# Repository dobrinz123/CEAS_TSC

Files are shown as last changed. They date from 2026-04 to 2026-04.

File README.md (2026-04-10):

# InkTime v6 — E-Paper Smartwatch

Smartwatch cu ecran e-paper, Bluetooth Low Energy si baterie LiPo reincarcabila prin USB-C.

**Curs:** TSC (Testarea Sistemelor de Calcul), Anul 3  
**Tool:** Fusion 360 Electronics (EAGLE format)  
**Producator:** JLCPCB — 4 straturi, stackup JLC04161H-7628, finish ENIG

---

## Block Diagram

```
                        USB-C (J4)
                           |
                     USBLC6-2SC6Y (D4)
                       ESD Protection
                           |
            +--------------+---------------+
            |                              |
      BQ25180 (IC3)                   nRF52840 (U1)
      LiPo Charger                  BLE5 + ARM M4F
      I2C addr 0x6A                    64MHz MCU
            |                     /    |    |    \
        LiPo Battery         SPI   I2C  GPIO  USB
            |                  |     |    |
      MAX17048 (U1)        E-Paper  Bus  Buttons
      Fuel Gauge           Display  |    (3x SW)
      I2C addr 0x36       1.54"    |
            |              GDEW0154 |
      RT6160 (IC2)              +---+---+---+
      Buck-Boost DC/DC         |   |   |   |
      3.3V Output          BMA421 MAX  BQ  DRV2605
                           IMU  17048 25180 Haptic
                           0x18  0x36 0x6A  0x5A
                                            |
                                        Shaker Motor
                                        LCM1027B3605F
```

---

## Specificatii

| Parametru | Valoare |
|---|---|
| MCU | nRF52840-QIAA (BLE 5.0, ARM Cortex-M4F, 64MHz) |
| Display | GDEW0154M09 1.54" e-paper (200x200px) |
| Baterie | LiPo 250mAh, BQ25180 charger |
| IMU | BMA421 accelerometru + step counter |
| Haptics | DRV2605L + LCM1027B3605F motor ERM |
| Fuel Gauge | MAX17048 LiPo gauge |
| DC/DC | RT6160 buck-boost, 3.3V output |
| USB | USB-C (KH-TYPE-C-16P), USBLC6-2SC6Y ESD |
| Debug | TC2030-IDC TagConnect SWD |
| PCB | 46x35mm, 4 straturi, 1.6mm, ENIG |

---

## Stackup PCB

| Strat | Functie | Cupru |
|---|---|---|
| F.Cu (Top) | Semnal + Componente | 1oz (35um) |
| In1.Cu | Plan GND | 0.5oz (17.5um) |
| In2.Cu | Plan 3V3 | 0.5oz (17.5um) |
| B.Cu (Bottom) | Rutare semnal | 1oz (35um) |

---

## Structura Proiect

```
Hardware/
|-- inktime_v6.sch                # Schematic EAGLE
|-- inktime_v6.brd                # PCB layout (46x35mm, 4 straturi)
Manufacturing/
|-- inktime_v6_gerbers.zip        # Fisiere Gerber pt JLCPCB
|-- inktime_v6_BOM_jlcpcb.csv    # Bill of Materials (part numbers LCSC)
|-- inktime_v6_CPL_jlcpcb.csv    # Pick-and-Place (coordonate componente)
Mechanical/
|-- inktime_v6_cas.f3d            # Model 3D Fusion 360 (carcasa + componente)
|-- inktime_v6.step               # Export STEP
Images/
|-- Baterie.png                   # Model 3D baterie LiPo
|-- Carcasa_ceas.png              # Randare carcasa (vedere 1)
|-- Carcasa_ceas_2.png            # Randare carcasa (vedere 2)
|-- Ecran_e_paper.png             # Model 3D ecran e-paper
|-- Model_PCB.png                 # Model 3D PCB cu componente
|-- Motor.png                     # Model 3D motor vibratii
|-- Randare_PCB.png               # Randare PCB complet
LICENSE
README.md
```

---

## Note Fabricatie

- **Producator**: JLCPCB 4 straturi, stackup JLC04161H-7628
- **Finish**: ENIG (Electroless Nickel Immersion Gold)
- **Grosime PCB**: 1.6mm
- **Cupru**: 1oz exterior, 0.5oz interior
- **Componente**: Toate pe stratul TOP, asamblare SMT
- **Montare manuala**: retea matching RF, test pads, conector FPC (J1), TagConnect (J3), motor vibratii

---

## Autor

Dobrin David — TSC (Testarea Sistemelor de Calcul), 2026

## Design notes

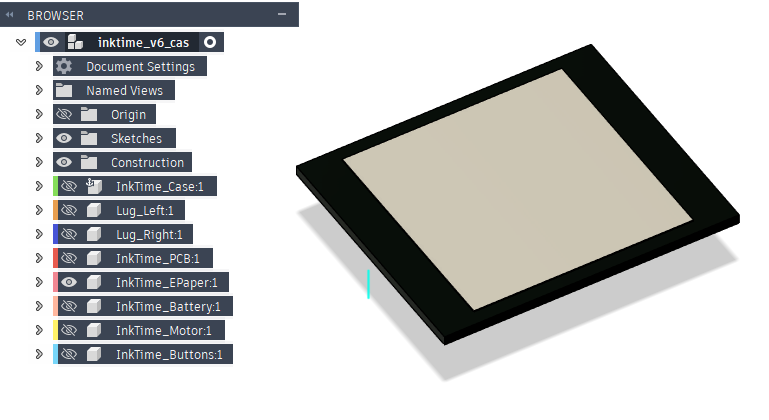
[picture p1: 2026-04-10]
Images/Ecran_e_paper.png

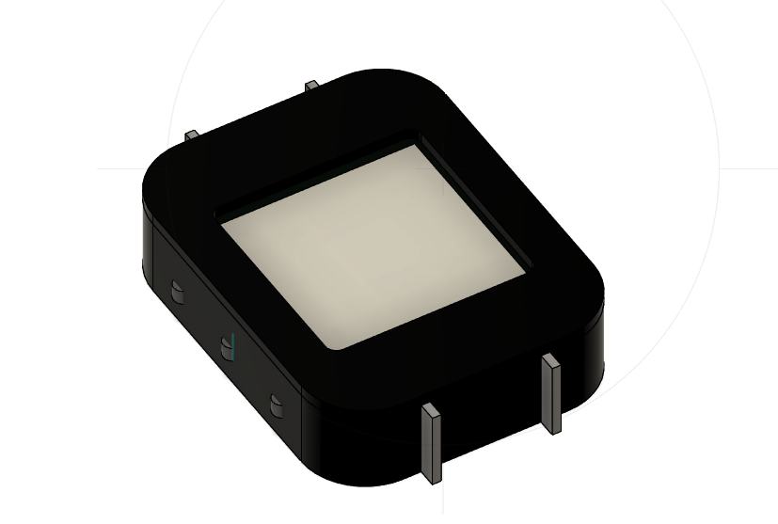
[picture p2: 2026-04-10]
Images/Carcasa_ceas_2.png

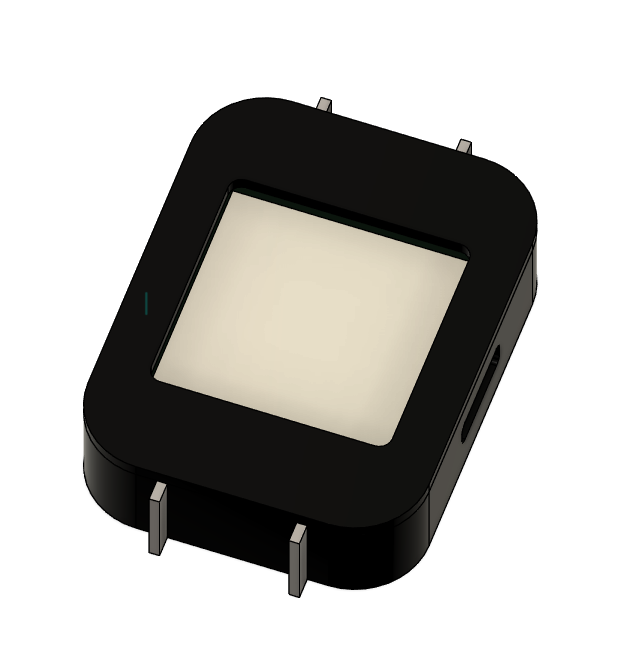
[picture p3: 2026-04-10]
Images/Carcasa_ceas.png

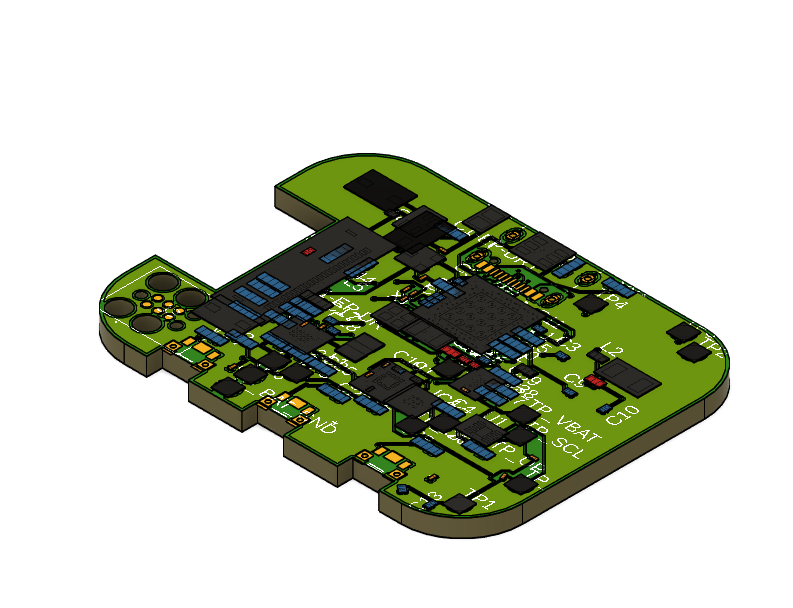
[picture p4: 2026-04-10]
Images/Randare_PCB.png

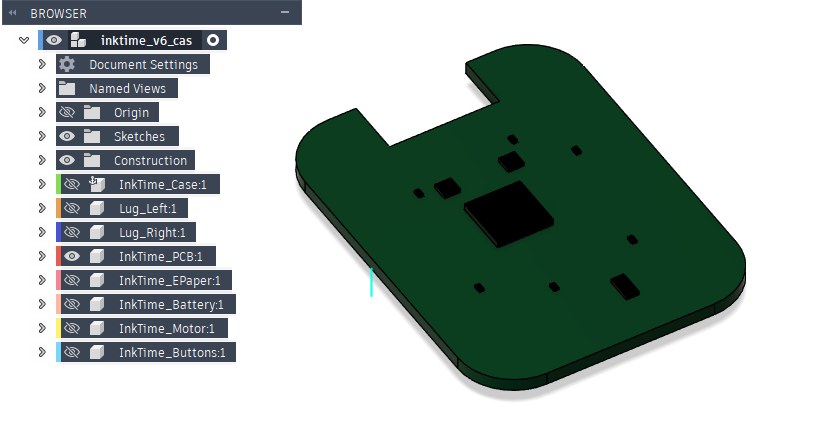
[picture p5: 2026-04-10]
Images/Model_PCB.png

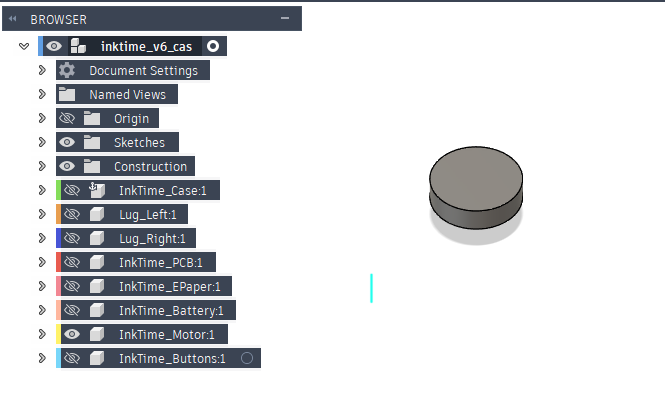
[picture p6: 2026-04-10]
Images/Motor.png

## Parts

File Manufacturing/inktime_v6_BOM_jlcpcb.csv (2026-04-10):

Comment | Designator | Footprint | LCSC Part #
0 | R1,R2,R3 | 0201 | C17168
0 | SJ1 | SJ | C17168
0.1uF | C2,C23,C26,C31 | 0402 | C14663
0.47 | R6 | 0201
1.0uF | C15 | 0402 | C15849
100nF | C12,C19,C5,C7,C8 | 0201 | C14663
100pF | C11 | 0201 | C14858
10K | R10,R11,R12,R13,R14,R16,R8,R9 | 0201 | C25744
10uF | C1-EP-DR,C24,C39 | 0402 | C15712
10uH | L2,L3 | 0402 | C408494
12pF | C17,C18,U$4,U$5 | 0201 | C30379
1pF | C1,C3 | 0201
1uF | C27,C28,C29,C37,C38,C4 | 0402 | C15849
1uF/50V | U$3 | 0201 | C15849
1uF/50V | C32,C34,C35,C36,C40,C41,C42,C43,C44 | 0402 | C15849
2.2 | R7 | 0201 | C25879
2025-10-22_07-23-44_LIBRARY_EVP-AKE31ASW_EVP-AKE31A_PAN | SW1,SW2,SW3 | SW-SMD-3x4
20V/4.2A/52mohm/1.4W | Q2 | SOT23-3
22uF | C25,C33 | 0402 | C59461
2450AT18B100E_2450AT18B100E | ANT1 | 0402 | C89965
3.9nH | U$2 | 0402 | C95912
32.768kHz | X2 | SMD3215 | C32346
32MHz | X1 | SMD3215 | C9001582
3K3 | R4,R5 | 0201 | C25890
4.7uF | C14,C20,C21,C30,C6 | 0402
4.7uF/25V | C1-EP-DR1 | 0402
47nF | C16 | 0201 | C14663
503480-2400_503480-2400 | J1 | FPC-24
68uH | L5 | 0201 | C132330
820pF | C9 | 0201 | C14858
BMA423_BMA423 | IC1 | LGA-12 | C5242966
BQ25180YBGR_BQ25180YBGR | IC3 | DSBGA-8 | C2681936
DRV2605YZFR_DRV2605YZFR | IC4 | DSBGA-12 | C2682232
ESP32_C6_LIBRARY_3_USBLC6-2SC6Y | D4 | SOT-363 | C7519
ESP32_C6_LIBRARY_5_MBR0530 | D1,D2,D3 | SOD-123 | C242214
ESP32_C6_LIBRARY_6_SI1308EDL-T1-GE3 | Q1 | SOT-523 | C145065
ESP32_C6_LIBRARY_MAX17048G+T10 | U1 | DFN8-2x2 | C2682616
KH-TYPE-C-16P_KH-TYPE-C-16P | J4 | USB-C-16P | C165948
MLP2016SR47MT0S1_FTC252012SR47MBCA | L1 | 0402
N.C. | C10,C13,C22 | 0201
NORDIC_NRF_4_NRF52840_QF | U$1 | QFN-73 | C190794
RT6160AWSC_RT6160AWSC | IC2 | WLCSP-15 | C7065276
TC2030-IDC_TC2030-IDC | J3 | TC2030

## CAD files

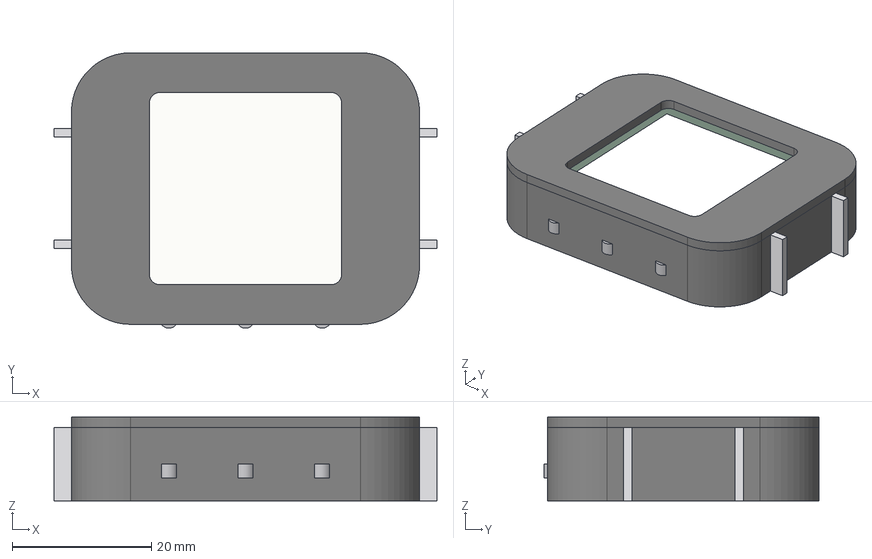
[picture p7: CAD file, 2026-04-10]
Mechanical/inktime_v6.step
55.0 x 39.5 x 12.0 mm

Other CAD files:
Mechanical/inktime_v6_cas.f3d

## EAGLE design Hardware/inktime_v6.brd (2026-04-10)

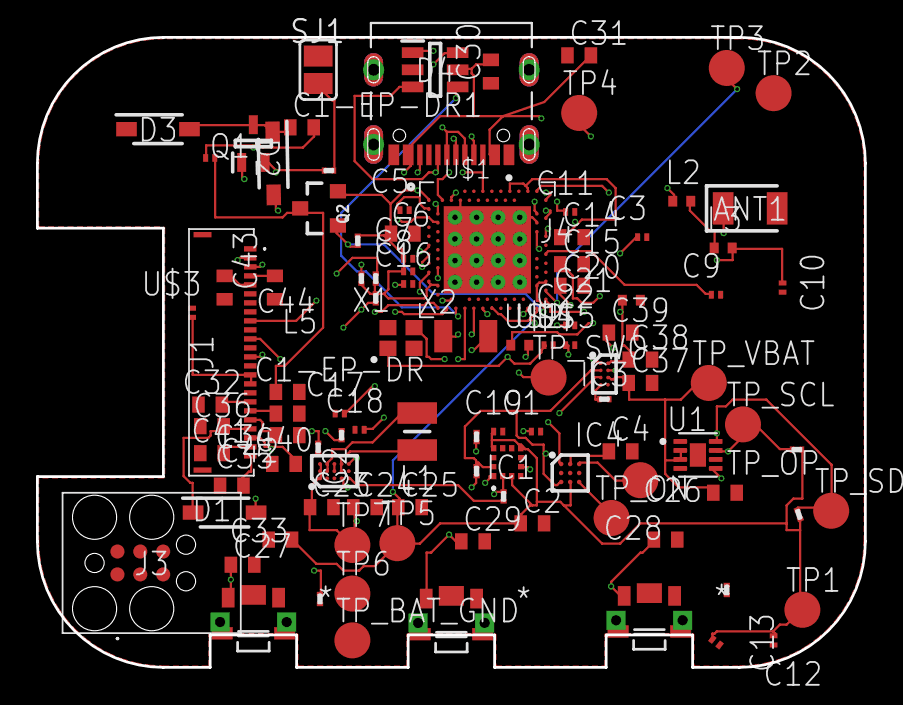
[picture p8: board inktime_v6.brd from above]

Board: 4 copper layers, 46.0 x 35.0 mm, 105 parts (0 on the bottom side), 70 nets.

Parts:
ANT1: 2450AT18B100E_2450AT18B100E; 2450AT18B100E_ANTC3216X140N
C1, C3: 1pF; NORDIC_NRF_3_RESC0201_L
C1-EP-DR, C24, C39: 10uF; ESP32_C6_LIBRARY_1_ESP32_WROVER_EAGLE-LTSPICE_C0402
C1-EP-DR1: 4.7uF/25V; ESP32_C6_LIBRARY_1_ESP32_WROVER_EAGLE-LTSPICE_C0402
C2, C23, C26, C31: 0.1uF; ESP32_C6_LIBRARY_1_ESP32_WROVER_EAGLE-LTSPICE_C0402
C4, C27, C28, C29, C37, C38: 1uF; ESP32_C6_LIBRARY_1_ESP32_WROVER_EAGLE-LTSPICE_C0402
C5, C7, C8, C12, C19: 100nF; NORDIC_NRF_3_RESC0201_L
C6, C14, C20: 4.7µF; ESP32_C6_LIBRARY_1_ESP32_WROVER_EAGLE-LTSPICE_C0402
C9: 820pF; NORDIC_NRF_3_RESC0201_L
C10, C13, C22: N.C.; NORDIC_NRF_3_RESC0201_L
C11: 100pF; NORDIC_NRF_3_RESC0201_L
C15: 1.0µF; ESP32_C6_LIBRARY_1_ESP32_WROVER_EAGLE-LTSPICE_C0402
C16: 47nF; NORDIC_NRF_3_RESC0201_L
C17, C18: 12pF; NORDIC_NRF_3_RESC0201_L
C21: 4.7µF; NORDIC_NRF_3_RESC0402_L
C25, C33: 22uF; ESP32_C6_LIBRARY_1_ESP32_WROVER_EAGLE-LTSPICE_C0402
C30: 4.7uF; ESP32_C6_LIBRARY_1_ESP32_WROVER_EAGLE-LTSPICE_C0402
C32, C34, C35, C36, C40, C41, C42, C43, C44: 1uF/50V; ESP32_C6_LIBRARY_1_ESP32_WROVER_EAGLE-LTSPICE_C0402
D1, D2, D3: ESP32_C6_LIBRARY_5_MBR0530; ESP32_C6_LIBRARY_5_SOD3716X135N
D4: ESP32_C6_LIBRARY_3_USBLC6-2SC6Y; ESP32_C6_LIBRARY_3_SOT95P280X145-6N
IC1: BMA423_BMA423
IC2: RT6160AWSC_RT6160AWSC; RT6160AWSC_BGA15C40P3X5_140X230X60
IC3: BQ25180YBGR_BQ25180YBGR; BQ25180YBGR_BGA8C40P2X4_100X155X50
IC4: DRV2605YZFR_DRV2605YZFR; DRV2605YZFR_BGA9C50P3X3_144X144X62
J1: 503480-2400_503480-2400; 503480-2400_5034802400
J3: TC2030-IDC_TC2030-IDC; TC2030-IDC_TC2030IDC
J4: KH-TYPE-C-16P_KH-TYPE-C-16P; KH-TYPE-C-16P_KINGHELM_KH-TYPE-C-16P
L1: MLP2016SR47MT0S1_FTC252012SR47MBCA; MLP2016SR47MT0S1_INDC2016X100N
L2, L3: 10µH; NORDIC_NRF_2_RESC0402_L
L5: 68uH; NORDIC_NRF_2_RESC0201_L
Q1: ESP32_C6_LIBRARY_6_SI1308EDL-T1-GE3; ESP32_C6_LIBRARY_6_SOT65P210X110-3N
Q2: 20V/4.2A/52mΩ/1.4W; ESP32_C6_LIBRARY_4_ESP32_C6_LIBRARY_4_ESP32_C6_LIBRARY_4_ES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
R1, R2, R3: 0; CPF0201D7K68C1_0201
R4, R5: 3K3; CPF0201D7K68C1_0201
R6: 0.47; CPF0201D7K68C1_0201
R7: 2.2; CPF0201D7K68C1_0201
R8, R9, R10, R11, R12, R13, R14, R16: 10K; CPF0201D7K68C1_0201
SJ1: 0; ESP32_C6_LIBRARY_7_JUMPER_SJ
SW1, SW2, SW3: 2025-10-22_07-23-44_LIBRARY_EVP-AKE31ASW_EVP-AKE3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; 2025-10-22_07-23-44_LIBRARY_SW_EVP-AKE31A_PAN
TP1, TP2, TP3, TP4, TP5, TP6, TP7: HECTOR_WATCH_1_TPTP20R; HECTOR_WATCH_1_TP20R
TP_BAT_GND: HECTOR_WATCH_1_TPTP20R; HECTOR_WATCH_1_TP20R
TP_ON: HECTOR_WATCH_1_TPTP20R; HECTOR_WATCH_1_TP20R
TP_OP: HECTOR_WATCH_1_TPTP20R; HECTOR_WATCH_1_TP20R
TP_SCL: HECTOR_WATCH_1_TPTP20R; HECTOR_WATCH_1_TP20R
TP_SDA: HECTOR_WATCH_1_TPTP20R; HECTOR_WATCH_1_TP20R
TP_SWO: HECTOR_WATCH_1_TPTP20R; HECTOR_WATCH_1_TP20R
TP_VBAT: HECTOR_WATCH_1_TPTP20R; HECTOR_WATCH_1_TP20R
U1: ESP32_C6_LIBRARY_MAX17048G+T10; ESP32_C6_LIBRARY_SON50P200X200X80-9N
U$1: NORDIC_NRF_4_NRF52840_QF; NORDIC_NRF_4_AQFN50P700X700X85_HS-74N
U$2: 3.9nH; NORDIC_NRF_2_RESC0402_L
U$3: 1uF/50V; NORDIC_NRF_3_RESC0201_L
U$4, U$5: 12pF; NORDIC_NRF_3_RESC0201_L
X1: 32MHz; NORDIC_NRF_BT-XTAL_2016_N
X2: 32.768kHz; NORDIC_NRF_1_XTAL_3215_N

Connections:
3V3: C2.1, C6.1, C7.1, C8.1, C12.1, C13.1, C14.1, C19.1, C25.1, C33.1, IC1.3, IC1.7, IC1.10, IC2.E3, IC4.C2, Q2.2, R4.1, R5.1, R10.2, R11.2, R12.2, R16.2, TP1.TP, TP5.TP, U$1.P$A18, U$1.P$A22, U$1.P$AD14, U$1.P$AD23, U$1.P$B1, U$1.P$W1, U$1.P$Y2
ALERT: U1.5, U$1.P$J24
D+: D4.4, U$1.P$AD6
D-: D4.6, U$1.P$AD4
DEC3: C11.1, U$1.P$D23
DEC4_6: C10.1, C15.1, C16.1, L3.2, U$1.P$B5, U$1.P$E24
DN: D4.1, J4.A7, J4.B7
DP: D4.3, J4.A6, J4.B6
EPD: J1.15, J1.16, U$3.2
EPD_3V3: C1-EP-DR.1, L5.1, Q2.3
EPD_BUSY: J1.9, U$1.P$AD12
EPD_CS: J1.12, U$1.P$K2
EPD_DC: J1.11, U$1.P$AD10
EPD_RST: J1.10, U$1.P$AC11
GDR: J1.2, Q1.1, R8.2
GND: C1.2, C1-EP-DR.2, C2.2, C3.2, C4.2, C5.2, C6.2, C7.2, C8.2, C9.2, C10.2, C11.2, C12.2, C13.2, C14.2, C15.2, C16.2, C17.1, C18.1, C19.2, C20.2, C21.2, C22.2, C23.2, C24.2, C25.2, C26.2, C27.2, C28.2, C29.2, C30.1, C31.1, C32.1, C33.2, C34.1, C35.1, C36.1, C37.2, C38.2, C39.2, C40.1, C41.1, C43.1, C44.1, D3.1, D4.2, IC1.8, IC1.9, IC2.B1, IC2.C1, IC2.C2, IC2.C3, IC3.D2, IC4.B1, IC4.B3, J1.8, J1.17, J1.MP1, J1.MP2, J4.A1_B12, J4.A12_B1, J4.SH1, J4.SH2, J4.SH3, J4.SH4, R3.1, R7.1, R8.1, R9.1, R13.1, R14.2, SJ1.1, SW1.1, SW2.1, SW3.1, TP6.TP, TP_BAT_GND.TP, U1.1, U1.4, U1.6, U1.9, U$1.P$74, U$1.P$75, U$1.P$76, U$1.P$77, U$1.P$78, U$1.P$79, U$1.P$80, U$1.P$81, U$1.P$82, U$1.P$83, U$1.P$84, U$1.P$85, U$1.P$86, U$1.P$87, U$1.P$88, U$1.P$89, U$1.P$90, U$1.P$B7, U$1.P$F23, U$3.1, U$4.2, U$5.2, X1.2, X1.4
GND3: IC1.1, R3.2
HAPTIC_EN: IC4.A1, U$1.P$U1
IMU_INT1: IC1.5, U$1.P$N1
IMU_INT2: IC1.6, U$1.P$P2
LX1: IC2.B2, IC2.B3, L1.1
LX2: IC2.D2, IC2.D3, L1.2
MOSI: J1.14, U$1.P$B13
unnamed: C5.1, U$1.P$C1
unnamed: C20.1, U$1.P$AC5
unnamed: ANT1.1, C1.1, C22.1, U$2.2
unnamed: C3.1, U$1.P$H23, U$2.1
unnamed: L2.2, L3.1
unnamed: U$1.P$A23, U$5.1, X1.3
unnamed: IC2.D1, R2.2
unnamed: C1-EP-DR1.2, D1.2, L5.2
unnamed: IC2.E1, R1.2
unnamed: C1-EP-DR1.1, D2.1, D3.2, Q1.3
unnamed: C9.1, U$1.P$N24
unnamed: IC3.D1, R9.2
unnamed: U$1.P$B24, U$4.1, X1.1
unnamed: R6.1, SJ1.2
unnamed: L2.1, U$1.P$B3
unnamed: C4.1, IC4.A2
unnamed: J4.A5, R13.2
unnamed: J4.B5, R14.1
unnamed: C43.2, J1.4
unnamed: C44.2, J1.5
unnamed: C32.2, J1.18
unnamed: C34.2, J1.19
unnamed: C35.2, J1.20
unnamed: C41.2, J1.23
unnamed: C42.2, J1.24
OUT+: IC4.A3, TP_OP.TP
OUT-: IC4.C3, TP_ON.TP
P0.00/XL1: C17.2, U$1.P$D2, X2.1
P0.00/XL2: C18.2, U$1.P$F2, X2.2
P0.13: C27.1, R10.1, SW1.2, U$1.P$AD8
P0.14: C28.1, R11.1, SW2.2, U$1.P$AC9
P1.01: Q2.1, R16.1, U$1.P$W24, U$1.P$Y23
P1.02: C29.1, R12.1, SW3.2
PMIC_INT: IC3.A1, U$1.P$T2
PREVGH: C36.2, D1.1, J1.21
PREVGL: C40.2, D2.2, J1.22
RESE: J1.3, Q1.2, R6.2
RESET: TP2.TP, U$1.P$AC13
SCK: J1.13, U$1.P$A12
SCL: IC1.12, IC3.B1, IC4.C1, R2.1, R4.2, TP_SCL.TP, U1.7, U$1.P$M2
SDA: IC1.2, IC3.C1, IC4.B2, R1.1, R5.2, TP_SDA.TP, U1.8, U$1.P$L1
SWDCLK: TP3.TP, U$1.P$AA24
SWDIO: TP4.TP, U$1.P$AC24
SWO: TP_SWO.TP, U$1.P$AD22
VBAT: C26.1, C37.1, IC3.C2, TP_VBAT.TP, U1.2, U1.3
VBUS: C21.1, C30.2, C31.2, C38.1, D4.5, IC3.A2, J4.A4_B9, J4.A9_B4, U$1.P$AD2
VREG: C23.1, C24.1, C39.1, IC2.A1, IC2.A2, IC2.A3, IC3.B2, TP7.TP

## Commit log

2026-04-10 InkTime v6 - E-Paper Smartwatch Design
    [inktime_v6.brd, inktime_v6.sch, inktime_v6.step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]
2026-04-10 Update BOM and CPL from final PCB
    [inktime_v6.brd, inktime_v6_BOM_jlcpcb.csv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]

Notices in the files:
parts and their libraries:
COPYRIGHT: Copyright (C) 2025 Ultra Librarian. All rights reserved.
